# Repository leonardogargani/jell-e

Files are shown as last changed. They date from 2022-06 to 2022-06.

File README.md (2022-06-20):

# Jell-E

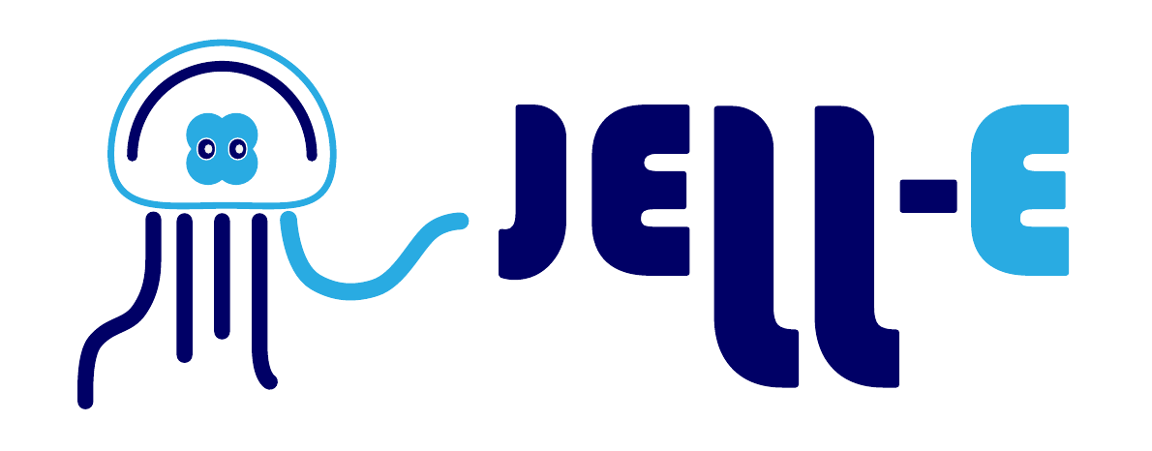
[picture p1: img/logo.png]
jell-e


Jell-E is a robot built for the Robotics & Design course at Politecnico di Milano, A.Y. 2021/2022.

The general theme of this year's edition is "Wearable Robot".

In particular, the goal is to make a robot able to engage interactions with third people, performing actions based on the behavior of both the wearer and other people.

To better know the Jell-E, take a look at:
- the [presentation slides](docs/presentation_slides.pdf)
- the [complete report](docs/complete_report.pdf)
- the [user manual](docs/user_manual.pdf)
- the [maintenance manual](docs/maintenance_manual.pdf)

## Repository structure

The repository is divided into the following directories:
- [esp32/](esp32/), containing the Arduino code that runs on the ESP32;
- [models/](models/), containing all the models (OpenSCAD and SolidWorks) for the parts of the robot;
- [schematic/](schematic/), containing the schematic of the circuit with all the sensors and actuators;
- [stl/](stl/), containing the STL files to print all the parts;
- [docs/](docs/), containing the user manual, the maintenance manual, some presentation slides, and the complete report.

## Team members

- Giorgio Brugali
- Alessandro Caruso
- Greta Corti
- Leonardo Gargani
- Yeran Liu

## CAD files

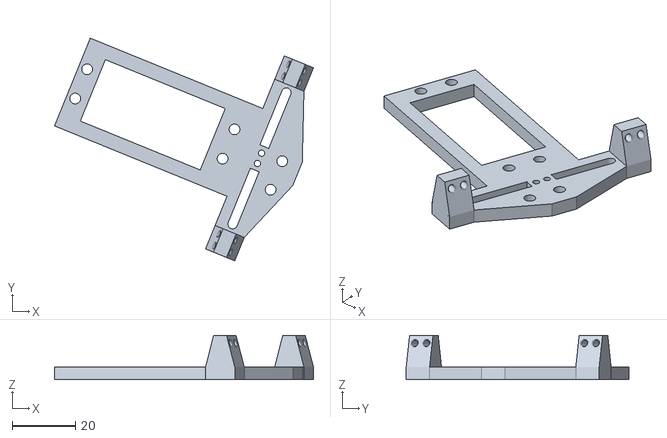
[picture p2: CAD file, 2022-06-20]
stl/solidworks/Assieme_Completo - ServoMotors_Main Adapter-2.STL
82.0 x 70.5 x 14.0

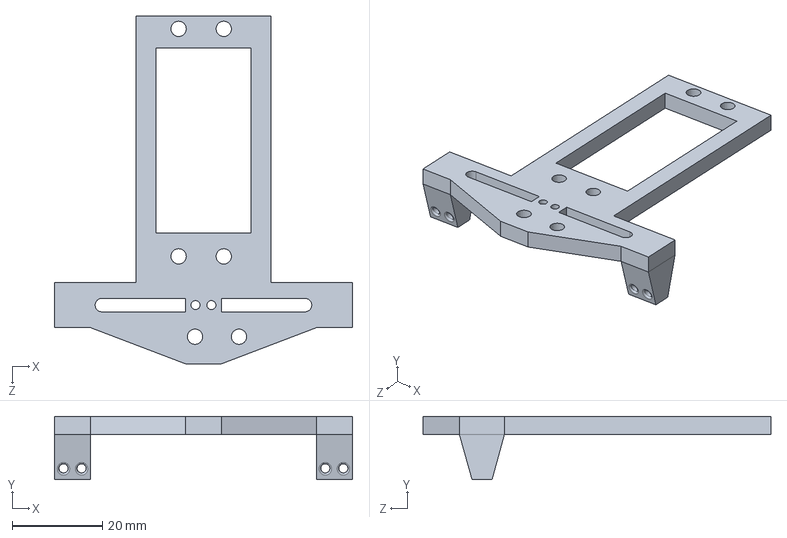
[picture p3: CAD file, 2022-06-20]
models/solidworks/ServoMotors_Main Adapter.SLDPRT
66.0 x 14.0 x 77.0 mm

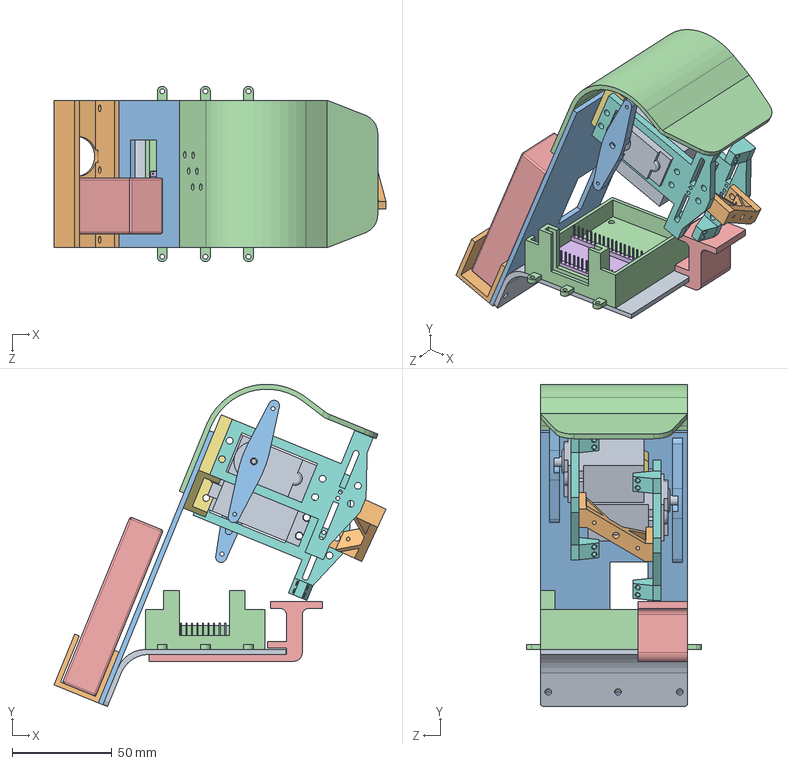
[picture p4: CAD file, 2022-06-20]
models/solidworks/Assieme_Completo.SLDASM
166.6 x 161.7 x 88.0 mm
Base_Shoulder Adapter
Cover_Battery and Switch
Cover_002 - Longer of 2.5
Cover_Upper Closure
External_Battery
Internal_ESP
ServoMotors_Adapter Back
ServoMotors_Main Adapter x 2
ServoMotor_Body x 2
ServoMotors_AdapterFront
ServoMotors_Adapter Wing x 2
Internal_Box_001
Extra Support

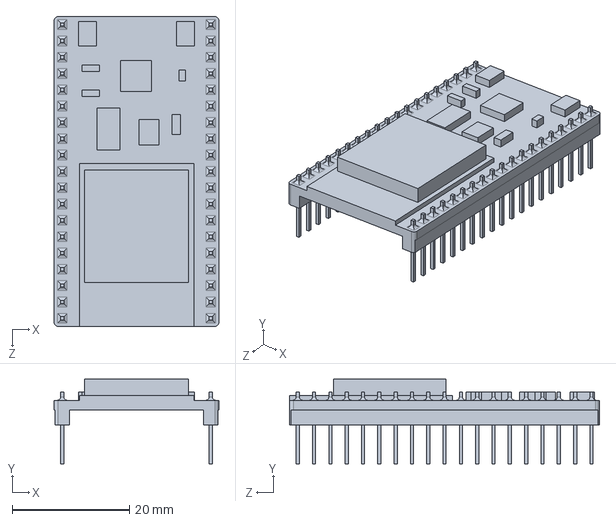
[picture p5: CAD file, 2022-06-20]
models/solidworks/Internal_ESP.SLDPRT
28.1 x 14.5 x 53.0 mm

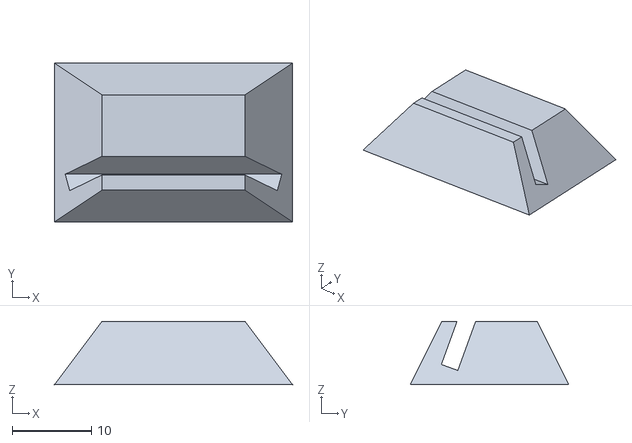
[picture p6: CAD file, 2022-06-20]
stl/openscad/plate_stand.stl
30.0 x 20.0 x 8.00

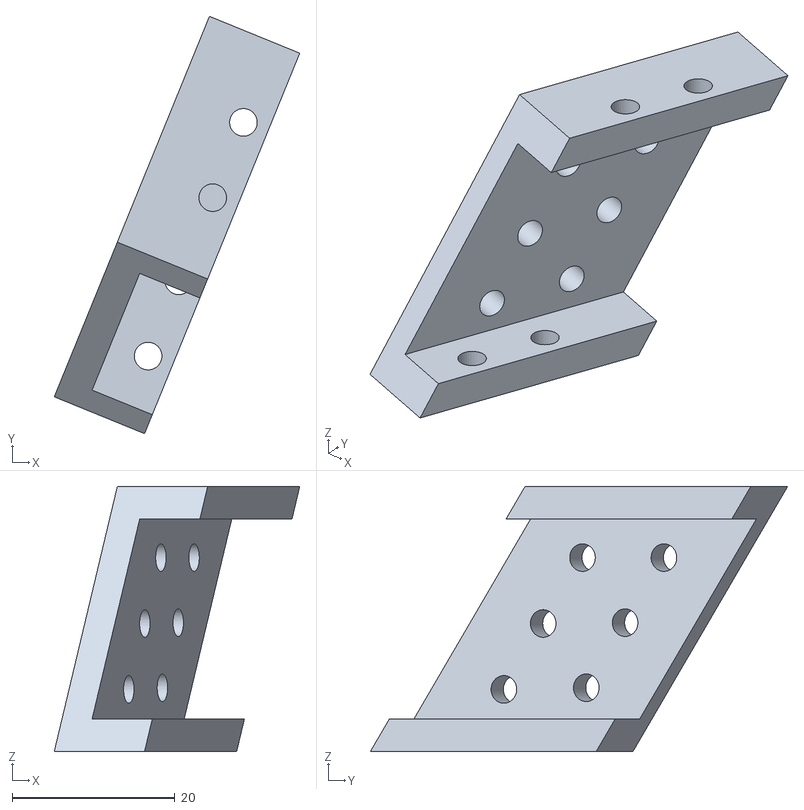
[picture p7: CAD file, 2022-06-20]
stl/solidworks/Assieme_Completo - ServoMotors_Adapter Back-1.STL
30.2 x 51.3 x 32.6

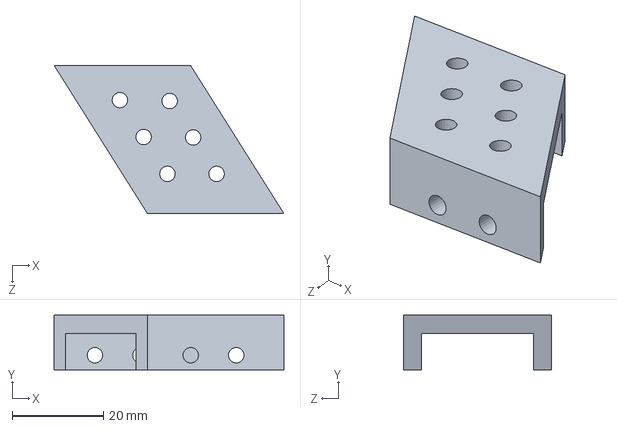
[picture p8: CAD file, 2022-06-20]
models/solidworks/ServoMotors_Adapter Back.SLDPRT
50.5 x 12.0 x 32.6 mm

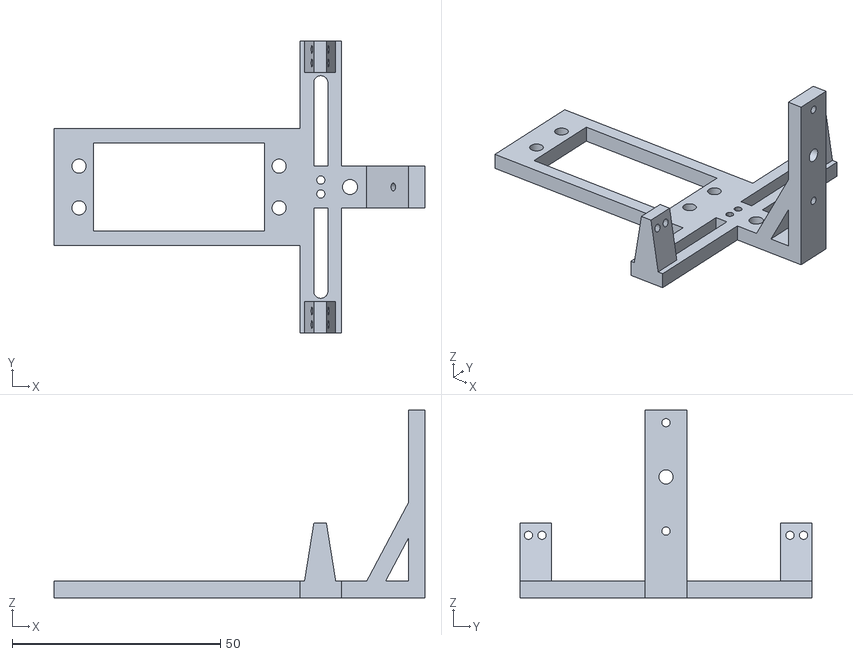
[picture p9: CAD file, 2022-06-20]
stl/openscad/servo_mount_high.stl
89.0 x 70.0 x 45.0

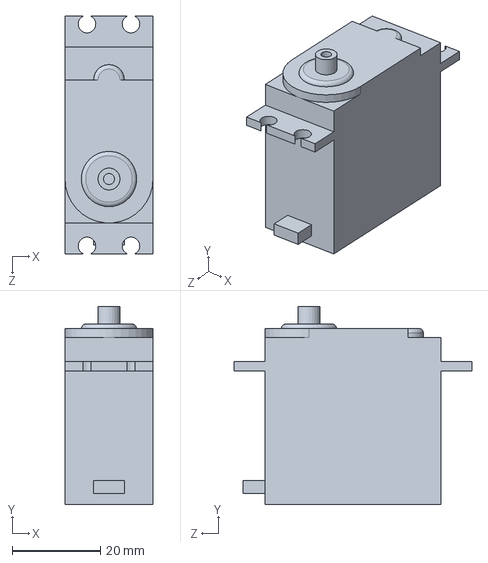
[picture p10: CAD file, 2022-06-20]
models/solidworks/ServoMotor_Body.SLDPRT
20.0 x 45.0 x 54.0 mm

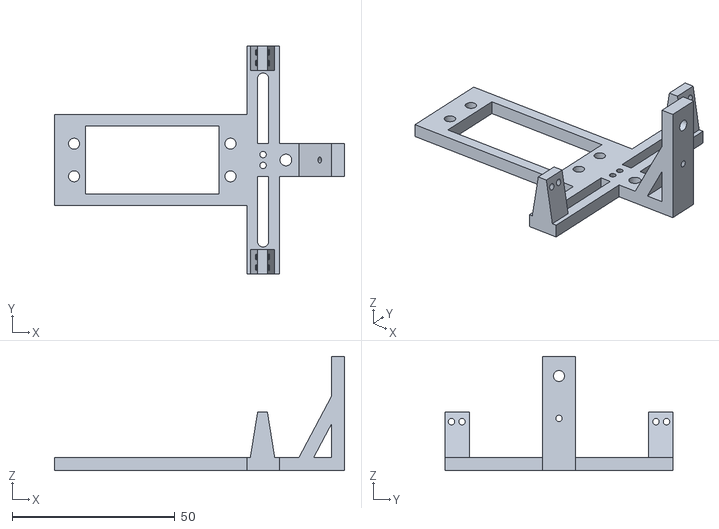
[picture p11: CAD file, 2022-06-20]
stl/openscad/servo_mount_low.stl
89.0 x 70.0 x 35.0

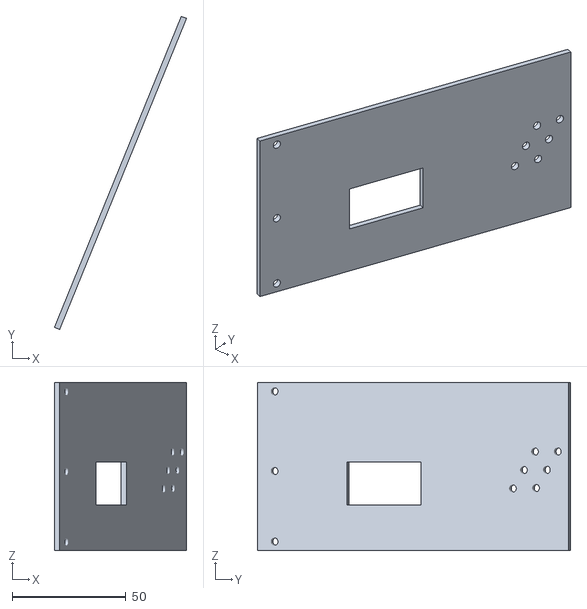
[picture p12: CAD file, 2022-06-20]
stl/solidworks/Assieme_Completo - Cover_002 - Longer of 2.5-1.STL
58.1 x 137.5 x 74.0

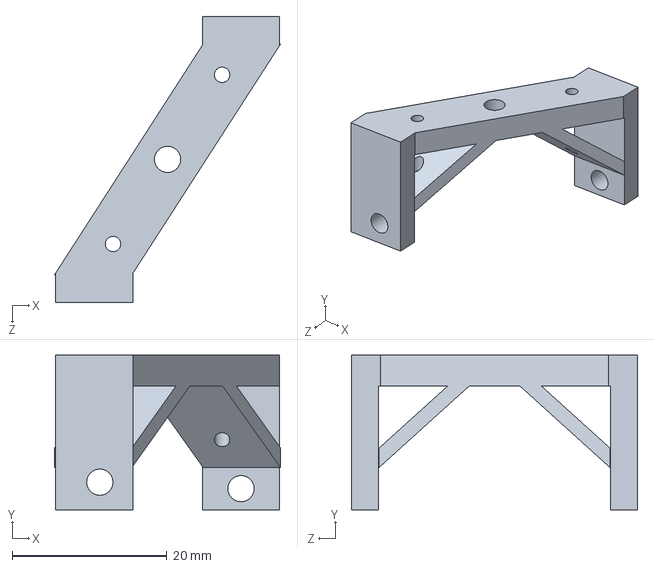
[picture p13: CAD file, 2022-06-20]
models/solidworks/ServoMotors_AdapterFront.SLDPRT
29.2 x 20.0 x 37.0 mm

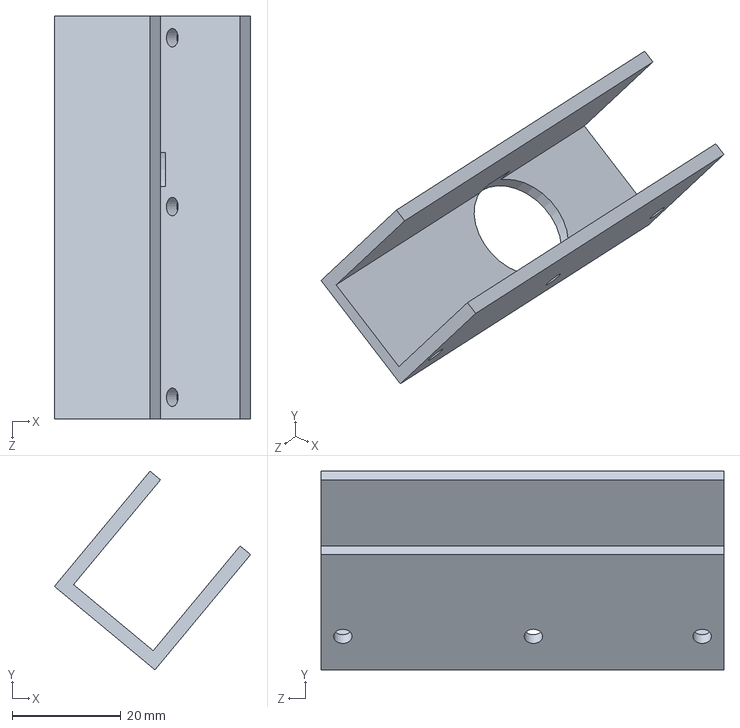
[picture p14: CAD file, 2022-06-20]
models/solidworks/Cover_Battery and Switch.SLDPRT
36.0 x 36.5 x 74.0 mm

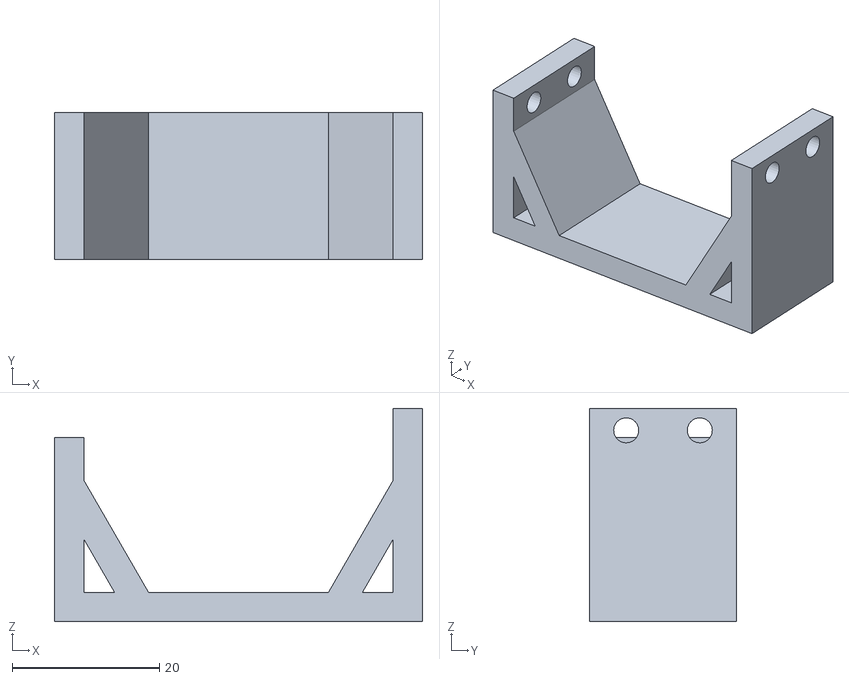
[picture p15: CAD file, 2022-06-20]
stl/openscad/arc_support.stl
50.0 x 20.0 x 29.0

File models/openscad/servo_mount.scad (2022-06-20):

include <lib/tentacle.scad>


servo_mount(high_vertical=false);

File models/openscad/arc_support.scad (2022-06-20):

include <lib/tentacle.scad>


arc_support();

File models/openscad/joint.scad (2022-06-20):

include <lib/tentacle.scad>


joint(joint_radius=16, last_joint=false);

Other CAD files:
stl/solidworks/Assieme_Completo - ServoMotors_Main Adapter-1.STL
stl/solidworks/Assieme_Completo - Internal_ESP-1.STL
stl/solidworks/Assieme_Completo - Cover_Upper Closure-1.STL
models/solidworks/Cover_002 - Longer of 2.5.SLDPRT
models/openscad/logo_plate.scad
models/openscad/plate_stand.scad
models/openscad/round_washer.scad
models/openscad/spring.scad
models/openscad/tip.scad
models/solidworks/Base_Shoulder Adapter.SLDPRT
models/solidworks/Cover_Upper Closure.SLDPRT
models/solidworks/External_Battery.SLDPRT
models/solidworks/Extra Support.SLDPRT
models/solidworks/Internal_Box_001.SLDPRT
stl/openscad/joint.stl
stl/openscad/logo_plate.stl
stl/openscad/round_washer.stl
stl/openscad/spring.stl
stl/solidworks/Assieme_Completo - Base_Shoulder Adapter-1.STL
stl/solidworks/Assieme_Completo - Cover_Battery and Switch-1.STL
stl/solidworks/Assieme_Completo - External_Battery-1.STL
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

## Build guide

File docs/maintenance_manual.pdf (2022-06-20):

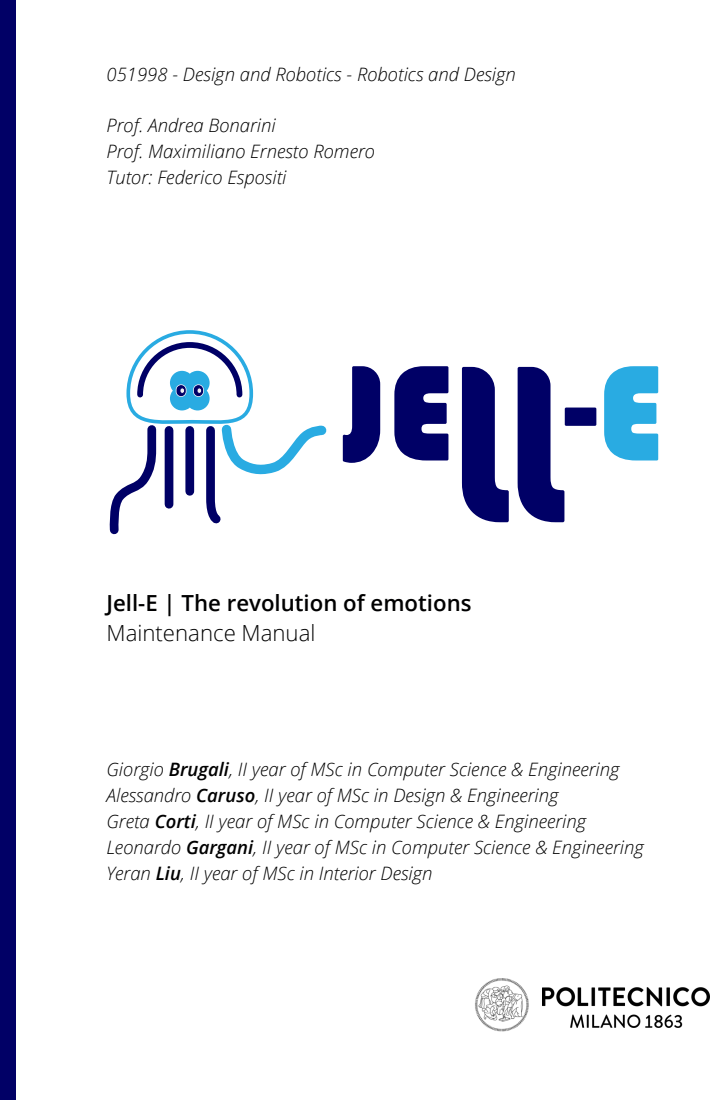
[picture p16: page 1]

051998 - Design and Robotics - Robotics and Design

Prof. Andrea Bonarini
Prof. Maximiliano Ernesto Romero
Tutor: Federico Espositi

Jell-E | The revolution of emotions
Maintenance Manual

Giorgio Brugali, II year of MSc in Computer Science & Engineering
Alessandro Caruso, II year of MSc in Design & Engineering
Greta Corti, II year of MSc in Computer Science & Engineering
Leonardo Gargani, II year of MSc in Computer Science & Engineering
Yeran Liu, II year of MSc in Interior Design

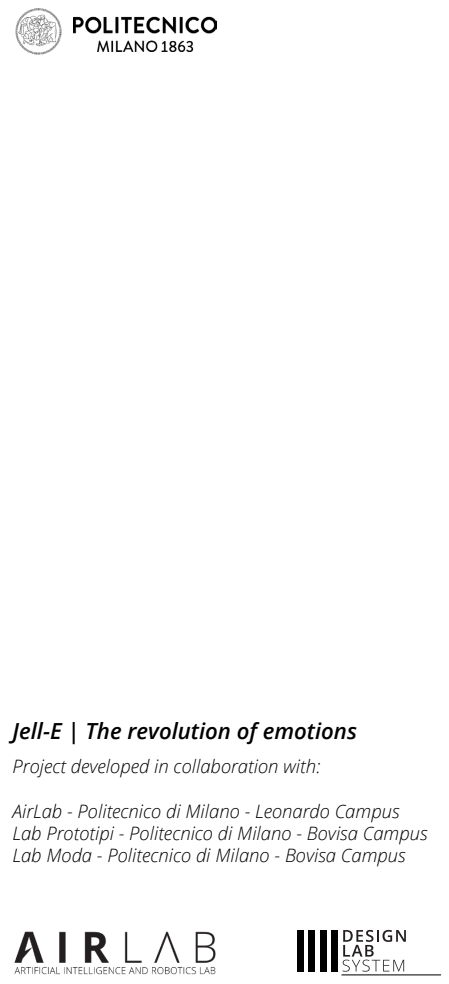
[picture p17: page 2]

Jell-E | The revolution of emotions
Project developed in collaboration with:
AirLab - Politecnico di Milano - Leonardo Campus
Lab Prototipi - Politecnico di Milano - Bovisa Campus
Lab Moda - Politecnico di Milano - Bovisa Campus

Jell-E | Maintenance Manual

### Circuit | Overview of the internal components Maintenance Manual

This manual aims at making the maintenance process simple. For an optimal analysis of the internal electrical components, a schematic diagram of the circuit is shown.

The complete circuit is composed by 2 servomotors; 1 LiPo battery (1700 mAh); 1 ESP board; 1 swtich; 1 step-down; 1 microphone, 1 limit switch (finecorsa - ITA); 10 LEDs on a RGB strip lights and 20 LEDs obtained

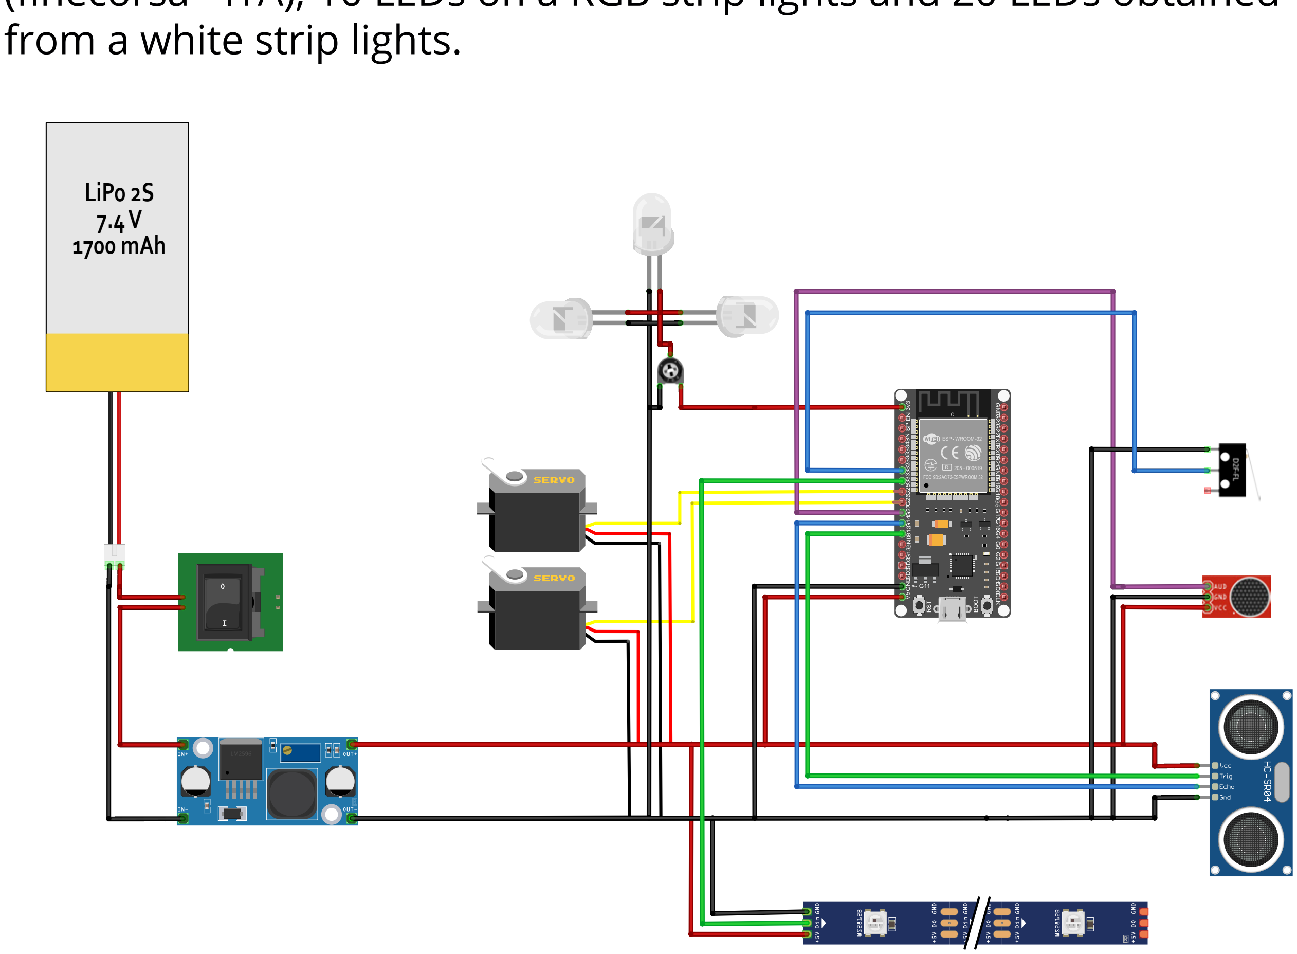
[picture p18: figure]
LiPo 2S 7.4 V 1700 mAh; from a white strip lights.

The battery needs to be recharged if it goes under 7.40 V otherwise the electronic circuit could not work properly. In case of battery change, place it correctly in the robot case as shown in the picture.
Connect the battery to its own connector and press the button under the case to turn on the robot. After 3 seconds from the switching the robot is ready to interact, as is possible to see the eyes leds start the “breath” gesture.

Remove the battery if the robot is going to be not used for a long time.

051998 - Robotics & Design - 2022

### Board | Pins and connectors Color code

Connections of sensors and actuators to the board are not interchangeable. To connect them correctly it is necessary to match the right colors (red, black, blue and white) and the same number of pins (two, three, and four) for each connector.

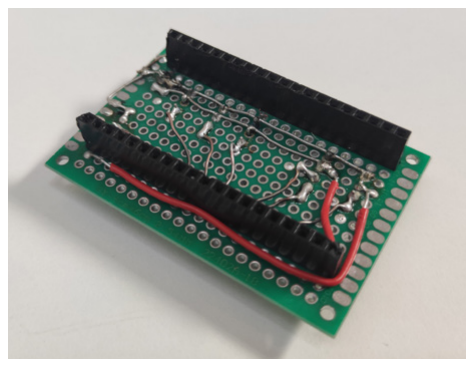
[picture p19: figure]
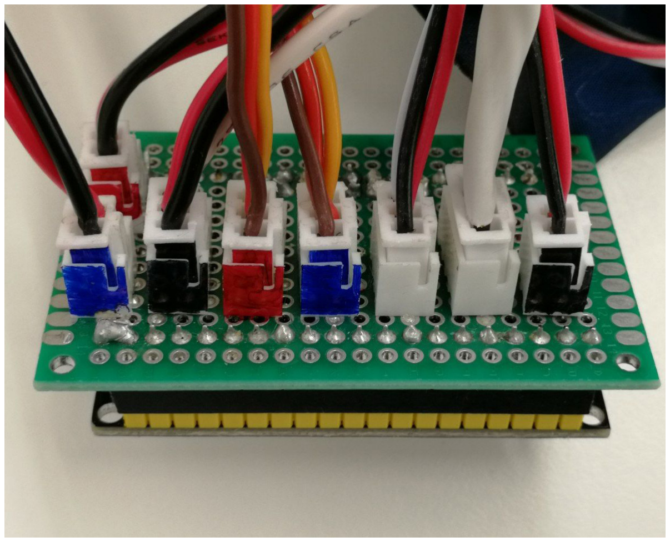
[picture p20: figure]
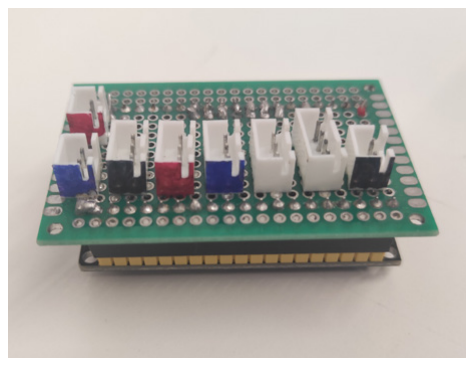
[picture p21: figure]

The existing 4-pins connector is the only one present on the board, and it is attached to the ultra sonic sensor. There are four 3-pins connectors and three 2-pins connector. The following scheme is provided to an optimal user experience.
1 - Limit switch
2 - Step down
3 - LED Strip
4 - Servo motor
5 - Servo motor
6 - Microphone
7 - Ultra sonic
8 - Lights

### JST connectors

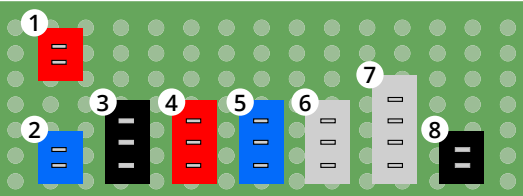
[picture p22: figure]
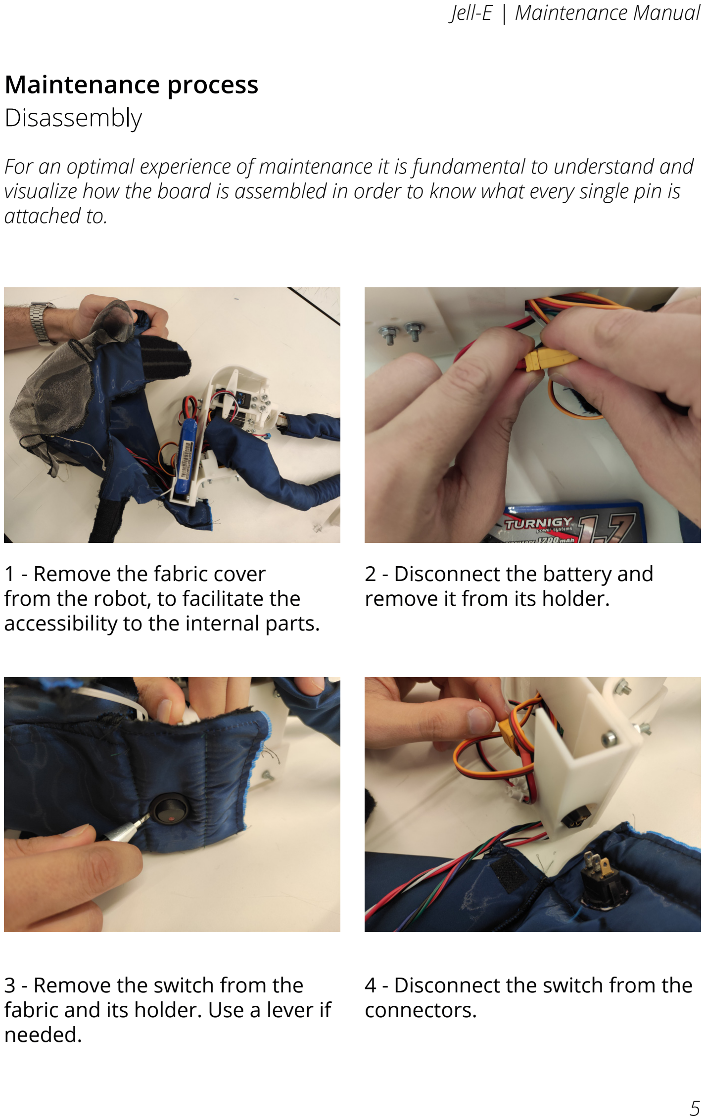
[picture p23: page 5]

Jell-E | Maintenance Manual

### Maintenance process Disassembly

For an optimal experience of maintenance it is fundamental to understand and visualize how the board is assembled in order to know what every single pin is attached to.

1 - Remove the fabric cover from the robot, to facilitate the accessibility to the internal parts.

3 - Remove the switch from the fabric and its holder. Use a lever if needed.

2 - Disconnect the battery and remove it from its holder.

4 - Disconnect the switch from the connectors.

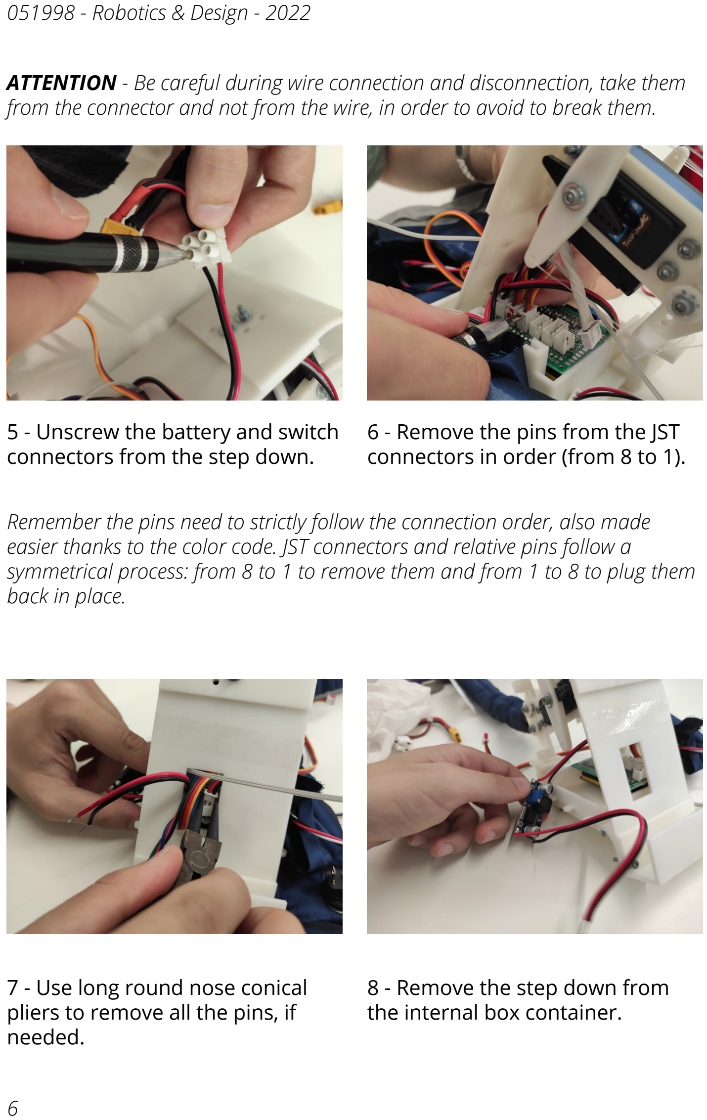
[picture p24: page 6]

051998 - Robotics & Design - 2022

ATTENTION - Be careful during wire connection and disconnection, take them from the connector and not from the wire, in order to avoid to break them.

Remember the pins need to strictly follow the connection order, also made easier thanks to the color code. JST connectors and relative pins follow a symmetrical process: from 8 to 1 to remove them and from 1 to 8 to plug them back in place.

5 - Unscrew the battery and switch
connectors from the step down.

7 - Use long round nose conical pliers to remove all the pins, if needed.

6 - Remove the pins from the JST connectors in order (from 8 to 1).

8 - Remove the step down from the internal box container.

Jell-E | Maintenance Manual

Bend a little bit the longer plastic plate with caution, and take out the stripboard. The microcontroller is connected above the stripboard, it is possible to remove it, be careful not to skew the pins. In case of reconnection, be careful to place with the right orientation, use as reference the red line of 5V.

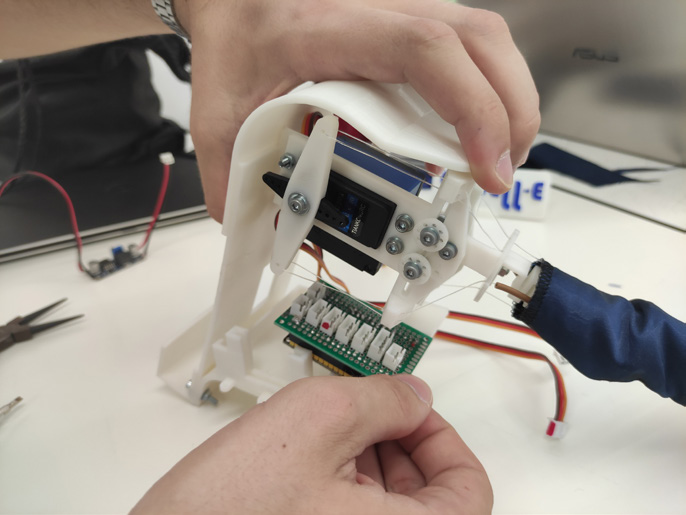
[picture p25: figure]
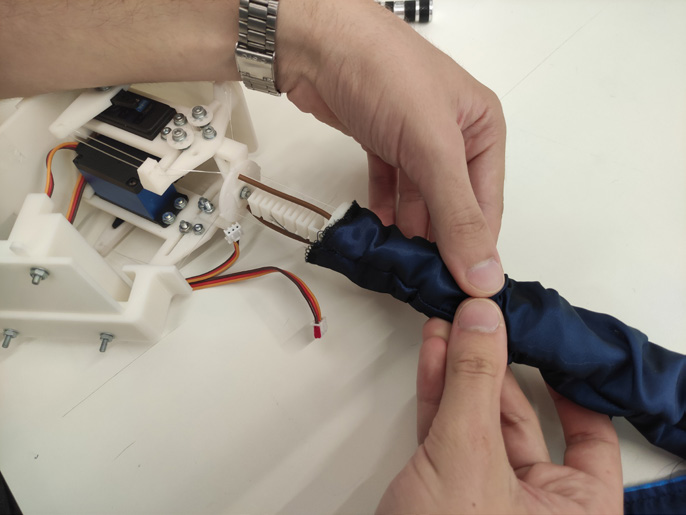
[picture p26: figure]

Due to the passage of time, fish lines that are connected to servos and used to control the mechanical tentacle movements may loosen. Use a screwdriver with the screws near the servo motors to regulate wire tensions.

9 - Remove the ESP board from
the box container, bending the
upper plate if needed.

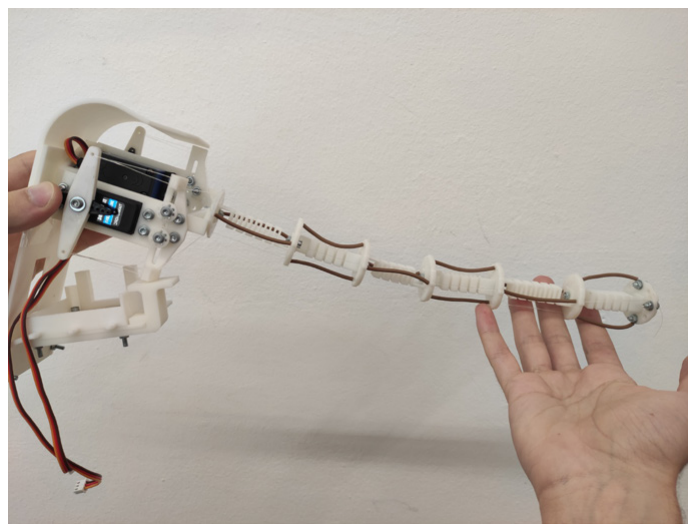
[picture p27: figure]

11 - Once you obtain the scheleton you can use a wrench to unscrew the internal nut that guides wires.

10 - Take off the covering fabric of the robotic tentacle. Pay attention to the nylon wires.

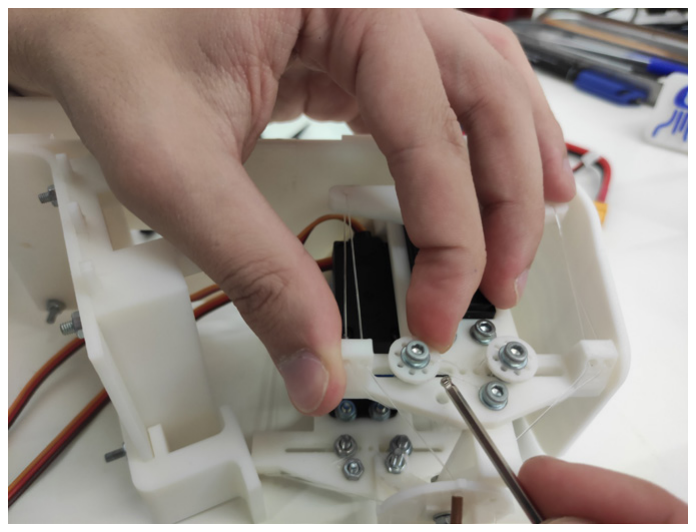
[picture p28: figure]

12 - Once loosen the nut, move the circular joint and move it along the rail to calibrate the tentacle.

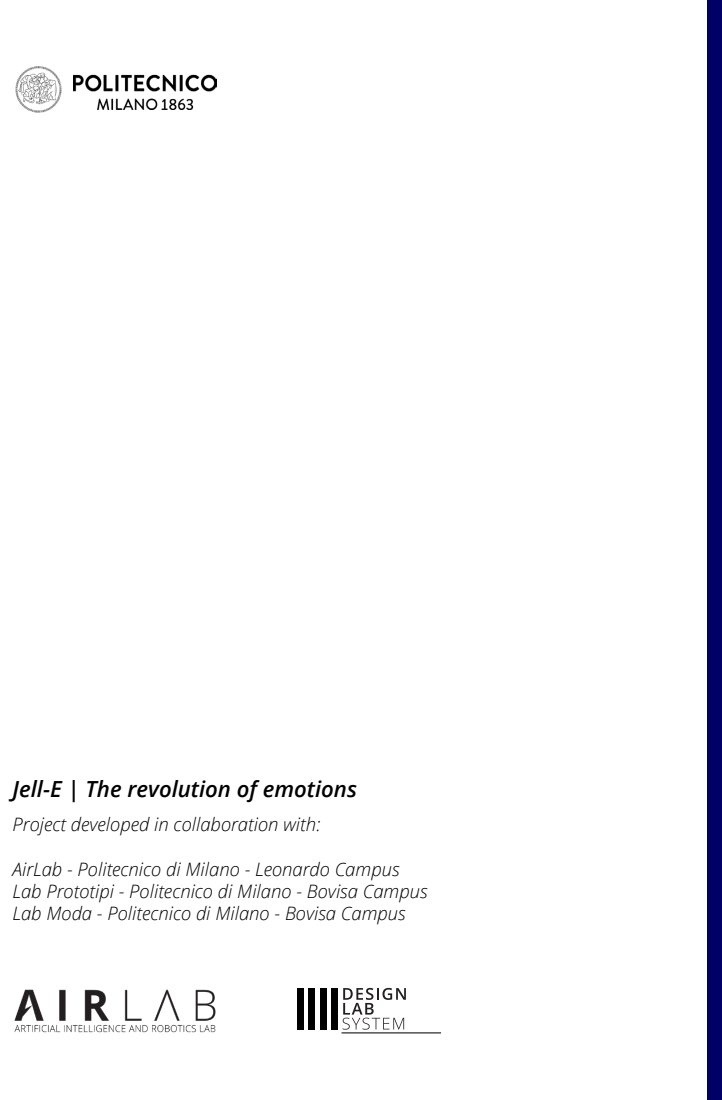
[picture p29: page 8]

Jell-E | The revolution of emotions
Project developed in collaboration with:
AirLab - Politecnico di Milano - Leonardo Campus
Lab Prototipi - Politecnico di Milano - Bovisa Campus
Lab Moda - Politecnico di Milano - Bovisa Campus

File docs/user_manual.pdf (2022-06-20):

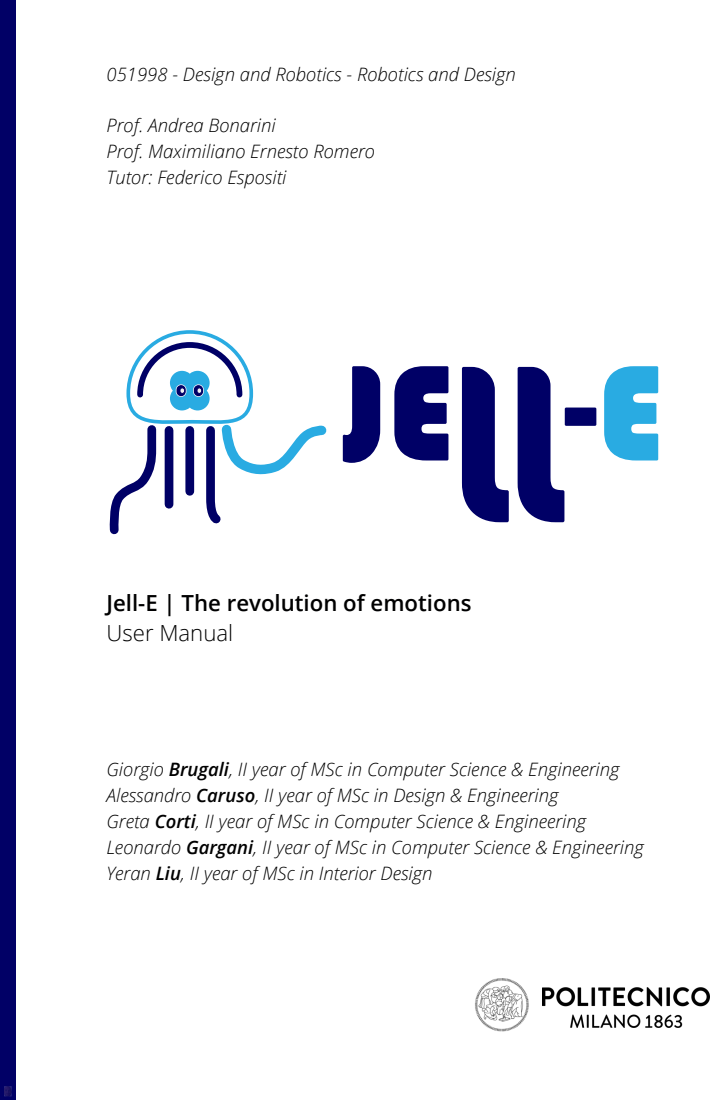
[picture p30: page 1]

051998 - Design and Robotics - Robotics and Design

Prof. Andrea Bonarini
Prof. Maximiliano Ernesto Romero
Tutor: Federico Espositi

Jell-E | The revolution of emotions
User Manual

Giorgio Brugali, II year of MSc in Computer Science & Engineering
Alessandro Caruso, II year of MSc in Design & Engineering
Greta Corti, II year of MSc in Computer Science & Engineering
Leonardo Gargani, II year of MSc in Computer Science & Engineering
Yeran Liu, II year of MSc in Interior Design


Jell-E | The revolution of emotions
Project developed in collaboration with:
AirLab - Politecnico di Milano - Leonardo Campus
Lab Prototipi - Politecnico di Milano - Bovisa Campus
Lab Moda - Politecnico di Milano - Bovisa Campus

Jell-E | User Manual

### Jell-E | User Journey User Manual

Jell-E is a wearable robot: it aims to be a mean for kids to communicate and express themselves. It can be considered as a called transitional object: the rapresentation of an object which kids use to make a transition from childhood to a first approach to the interactive world with others.

Jell-E has 2 eyes, which will recognize movement and proximity; a robotic tentacle, which will move according to the interactions provided, a long squeezable tentacle, with a botton on the tip and a microphone close to your shoulder to detect high sounds, lights around the eyes, which will change color according to the emotions Jell-E is feeling.

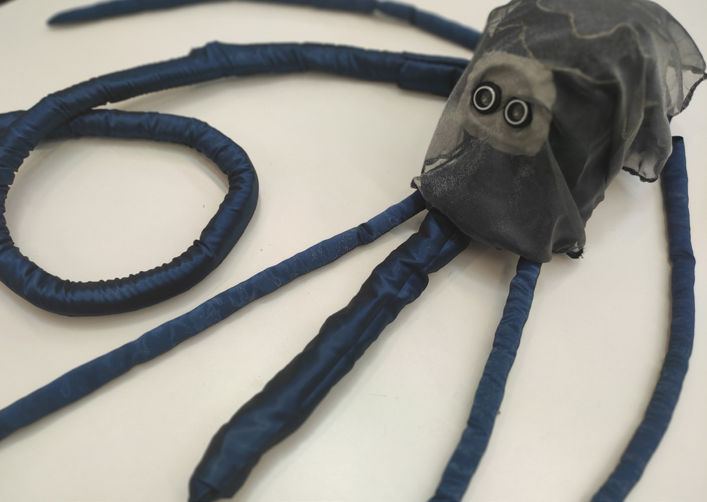
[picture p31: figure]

In this user manual you will find a precise guide which will explain in detail all the features of Jell-E, from how to dress it to how to make it work. The manual is intended for adults, to let them explain how to play with Jell-E and have an optimal experience.

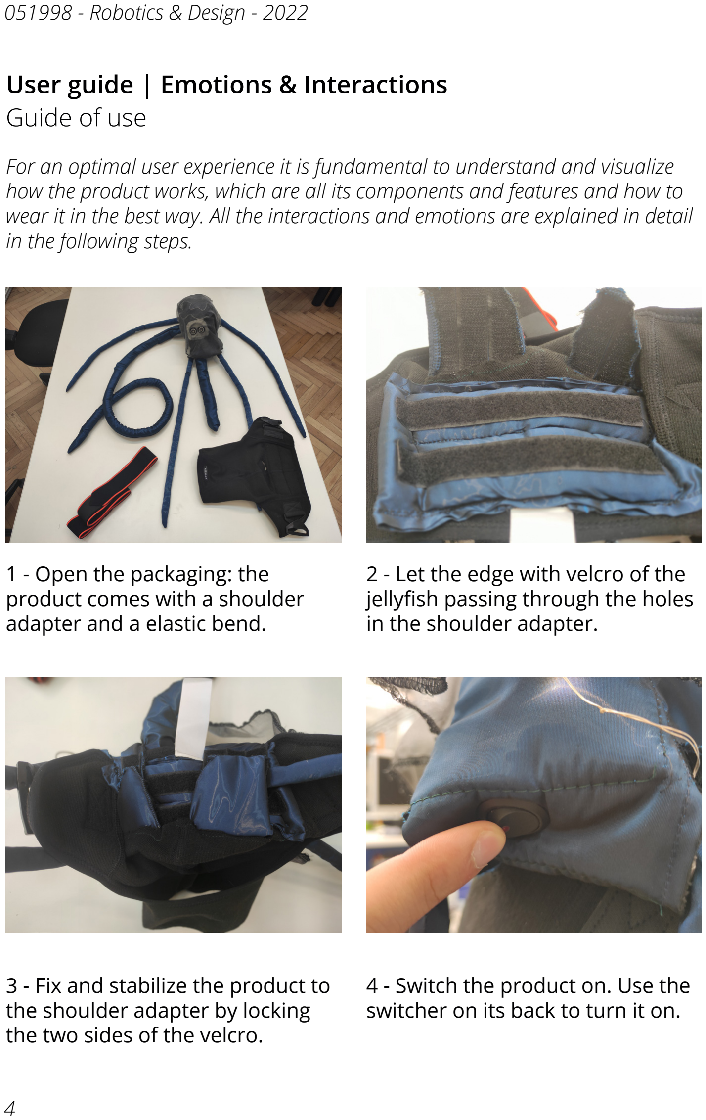
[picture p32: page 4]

051998 - Robotics & Design - 2022

### User guide | Emotions & Interactions Guide of use

For an optimal user experience it is fundamental to understand and visualize how the product works, which are all its components and features and how to wear it in the best way. All the interactions and emotions are explained in detail in the following steps.

1 - Open the packaging: the product comes with a shoulder adapter and a elastic bend.

3 - Fix and stabilize the product to the shoulder adapter by locking the two sides of the velcro.

2 - Let the edge with velcro of the jellyfish passing through the holes in the shoulder adapter.

4 - Switch the product on. Use the switcher on its back to turn it on.

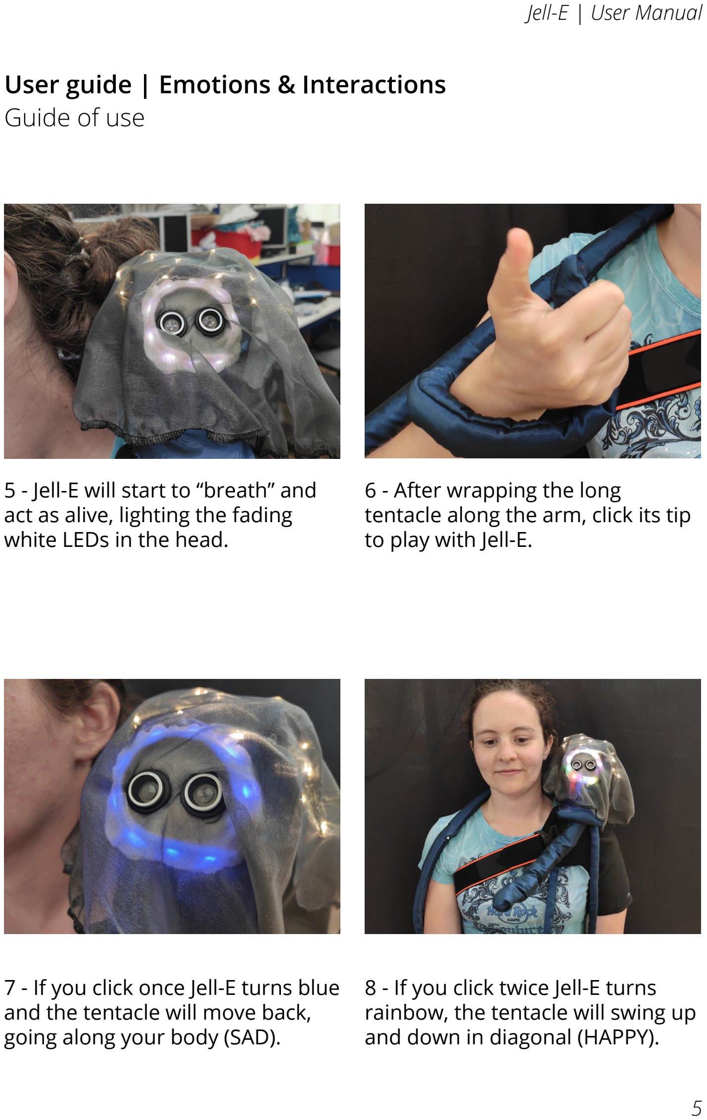
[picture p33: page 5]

Jell-E | User Manual

### User guide | Emotions & Interactions Guide of use

5 - Jell-E will start to “breath” and act as alive, lighting the fading white LEDs in the head.

7 - If you click once Jell-E turns blue and the tentacle will move back, going along your body (SAD).

6 - After wrapping the long tentacle along the arm, click its tip to play with Jell-E.

8 - If you click twice Jell-E turns rainbow, the tentacle will swing up and down in diagonal (HAPPY).

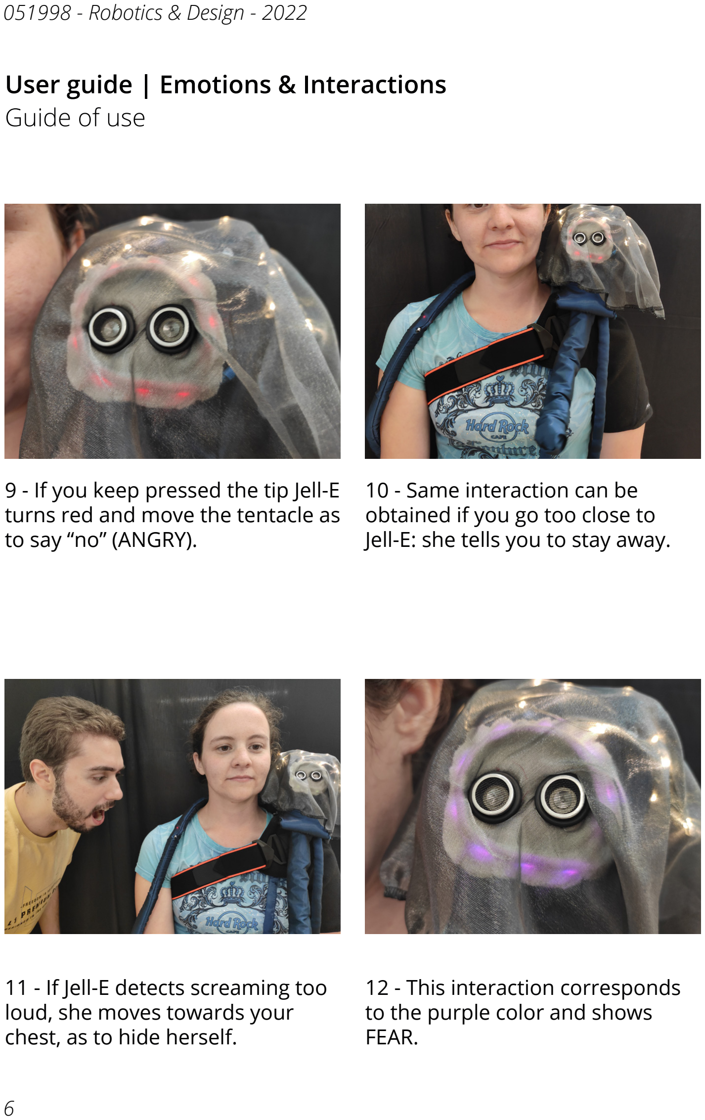
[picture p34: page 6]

051998 - Robotics & Design - 2022

9 - If you keep pressed the tip Jell-E turns red and move the tentacle as to say “no” (ANGRY).

11 - If Jell-E detects screaming too loud, she moves towards your chest, as to hide herself.

10 - Same interaction can be obtained if you go too close to Jell-E: she tells you to stay away.

12 - This interaction corresponds to the purple color and shows FEAR.

### User guide | Emotions & Interactions Guide of use

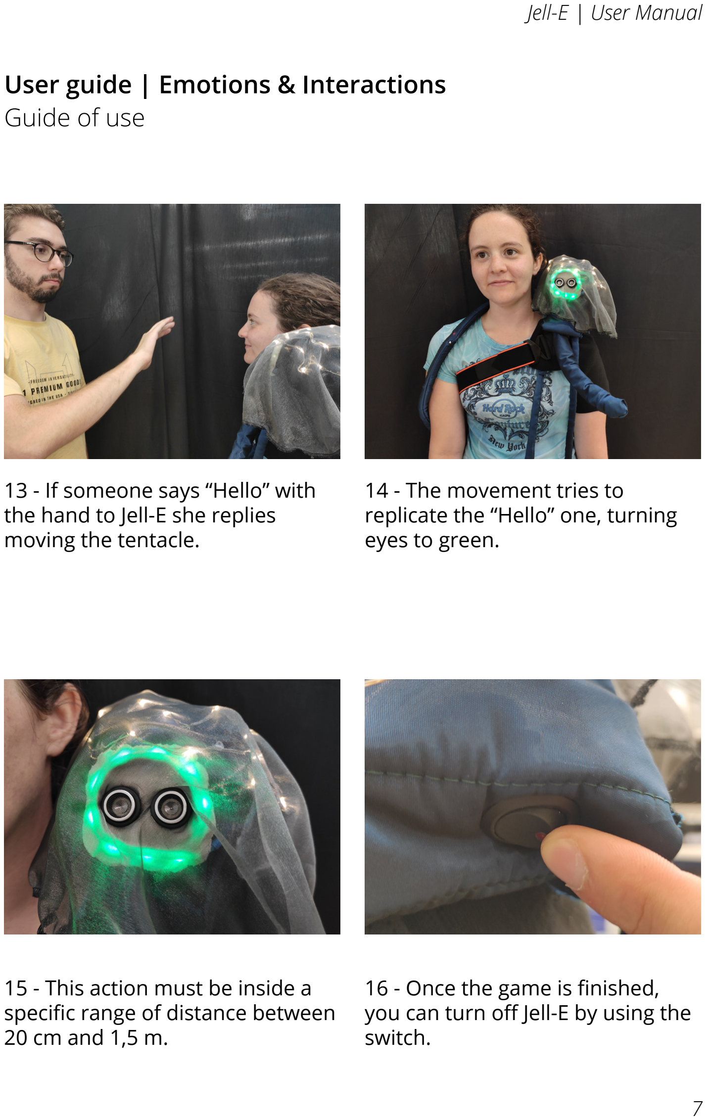
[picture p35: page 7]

Jell-E | User Manual

13 - If someone says “Hello” with the hand to Jell-E she replies moving the tentacle.

15 - This action must be inside a specific range of distance between 20 cm and 1,5 m.

14 - The movement tries to replicate the “Hello” one, turning eyes to green.

16 - Once the game is finished, you can turn off Jell-E by using the switch.

### User guide | Emotions & Interactions Guide of use


Jell-E | The revolution of emotions
Project developed in collaboration with:
AirLab - Politecnico di Milano - Leonardo Campus
Lab Prototipi - Politecnico di Milano - Bovisa Campus
Lab Moda - Politecnico di Milano - Bovisa Campus

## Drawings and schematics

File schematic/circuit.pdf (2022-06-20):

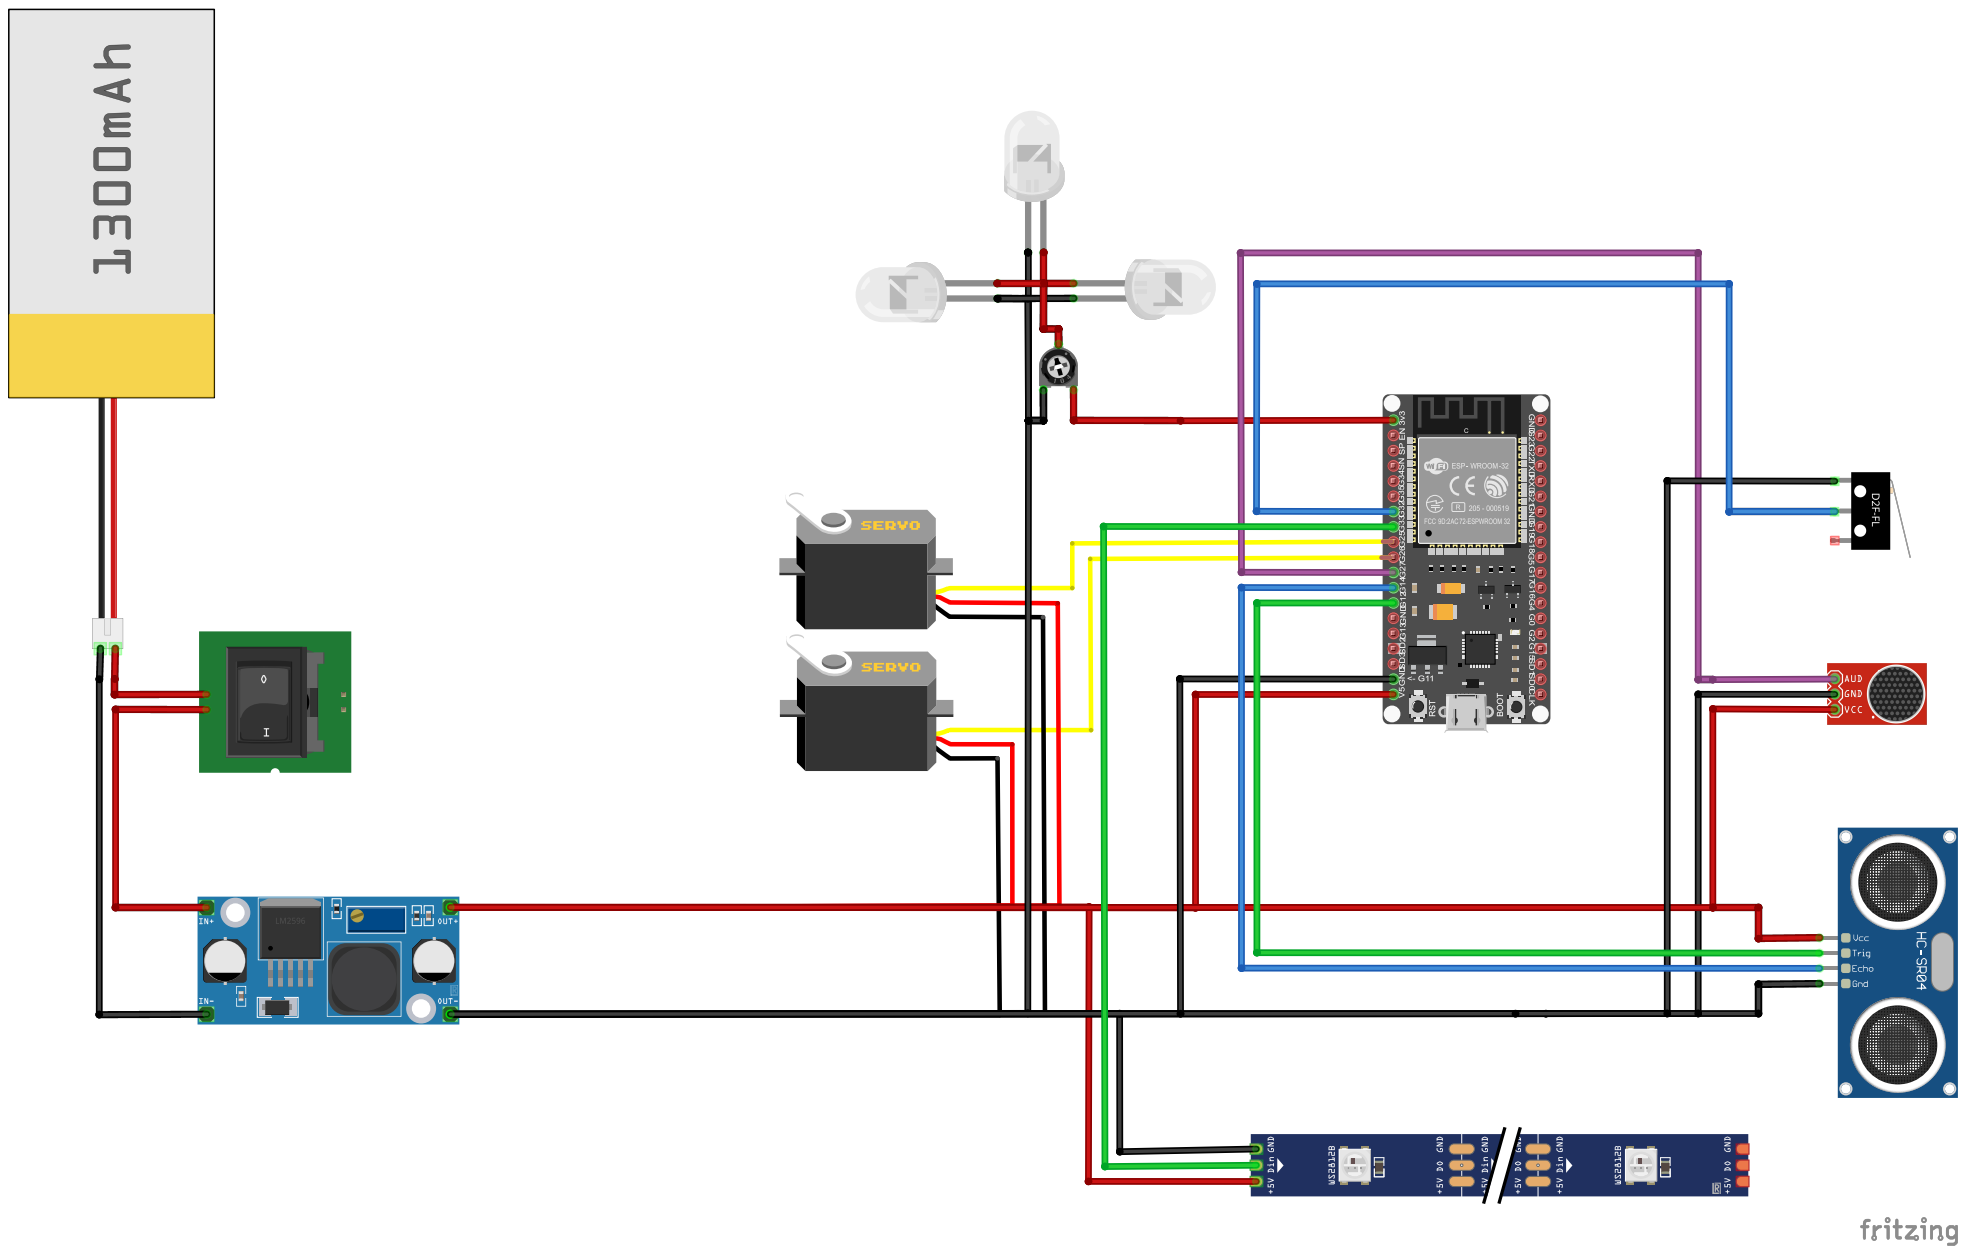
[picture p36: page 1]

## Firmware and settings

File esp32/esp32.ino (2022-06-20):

#include "Arduino.h"
#include "ServoEasing.hpp"
#include "Include/Devices.h"

#define ACTION_TIME 5000
#define WAITING_TIME 2000


// Objects that defines our sensors and actuators
Button button; 
Microphone mic_sensor;
UltrasonicSensor distance_sensor;
LEDStrip led_strip;
Tentacle tentacle;

unsigned long last_timestamp = 0;
unsigned long start_action_millis = 0;
unsigned long end_action_millis = 0;
int squeezes = 0;

// Flag used to disable sensors while a gesture is working
bool disable = false;

// Flags used to say which emotion is in use
bool hello_in_use = false;
bool stay_away_in_use = false;
bool curious_in_use = false;
bool scared_in_use = false;
bool can_breathe = true;


void setup()
{
  button.setup();
  mic_sensor.setup();
  distance_sensor.setup();
  led_strip.setup();
  tentacle.setup();
  delay(3000);
}


/**
 * @brief Function that detects and reacts to button pressure.
 * 
 */ 
void detectionPressure()
{
  if (!disable) {
    int button_state = button.readPress();
    if (button_state == 0 && (millis() - button.getLastDebounce()) > DEBOUNCE) {
      disable = true;
      can_breathe = false;
      last_timestamp = millis();
      button.setLastDebounce(last_timestamp);
      button.updatePressCounter(); // 1

      // Check if we have a second touch in 2 seconds
      while (millis() - last_timestamp < WAITING_TIME) {
        if (millis() - button.getLastDebounce() > DEBOUNCE) {
          button_state = button.readPress();
          if (button_state == 0) {
            // Touched twice
            start_action_millis = millis();
            button.setLastDebounce(millis());
            button.updatePressCounter(); // 2
            break;
          }
        }
      }

      // Check if we have a long press
      last_timestamp = millis();
      while (millis() - last_timestamp < WAITING_TIME / 4) {
        if (millis() - button.getLastDebounce() > DEBOUNCE) {
          button_state = button.readPress();
          if (button_state == 0) {
            // Long press
            start_action_millis = millis();
            button.setLastDebounce(millis());
            button.updatePressCounter(); // 3
            break;
          }
        }
      }
    }
  }

  squeezes = button.getPressCounter();
  switch (squeezes)
  {
  case 1:
    // Happy Gesture (one press)
    led_strip.sad();
    tentacle.sad();
    break;
  case 2:
    // Sad Gesture (two presses)
    led_strip.happy();
    tentacle.happy();
    break;
  case 3:
    // Angry Gesture (long press)
    led_strip.angry();
    tentacle.angry();
    break;
  }

  // Reset everything after the action is ended
  if (squeezes > 0) {
    if (millis() - start_action_millis > ACTION_TIME) {
      button.resetPressCounter();
      disable = false;
      can_breathe = true;
      tentacle.reset();
      led_strip.reset();
      end_action_millis = millis();
    }
  }
}


/**
 * @brief Function that detects and reacts to microphone readings.
 * 
 */
void detectSound()
{
  if (!disable) {
    int mic_read = mic_sensor.readMic();
    if (abs(mic_read - mic_sensor.computeAverage()) >= LOUD) {
      // Scared Gesture
      scared_in_use = true;
      disable = true;
      can_breathe = false;
      start_action_millis = millis();
      led_strip.scared();
      tentacle.scared();
    }
  }

  if (scared_in_use) {
    if (millis() - start_action_millis > ACTION_TIME) {
      scared_in_use = false;
      disable = false;
      can_breathe = true;
      tentacle.reset();
      led_strip.reset();
      end_action_millis = millis();
    }
  }
}


/**
 * @brief Function that detect and react to Ultrasonic sensor readings.
 * 
 */
void detectDistance()
{
  if (!disable) {
    int distance_read = distance_sensor.readDistance();
    distance_sensor.updateSwingCounter(distance_read);
    // Say Hello
    if (distance_sensor.getSwingCounter() >= MIN_SWING) {
      // Actions for saying hello
      hello_in_use = true;
      disable = true;
      can_breathe = false;
      start_action_millis = millis();
      distance_sensor.resetSwingCounter();
    }
    // Too near
    if (distance_read < MIN_DISTANCE) {
      // Stay away actions
      distance_sensor.resetSwingCounter();
      led_strip.angry();
      stay_away_in_use = true;
      disable = true;
      can_breathe = false;
      start_action_millis = millis();
    }
}

  if (hello_in_use) {
    led_strip.hello();
    tentacle.sayHi();
  } else if (stay_away_in_use) {
    tentacle.angry();
}

if (hello_in_use || stay_away_in_use) {
    if (millis() - start_action_millis > ACTION_TIME) {
        hello_in_use = false;
        stay_away_in_use = false;
        disable = false;
        can_breathe = true;
        distance_sensor.resetSwingCounter();
        tentacle.reset();
        led_strip.reset();
        end_action_millis = millis();
    }
  }
}

int swing_counter = 0;
int previous_distance = 0;


void loop()
{
  /************TOUCH CONTROL************/
  detectionPressure();

  /************SOUND CONTROL************/
  detectSound();

  /************DISTANCE CONTROL*********/
  detectDistance();

  /************BREATH CONTROL***********/
  if (can_breathe) {
    led_strip.breath();
  }

}

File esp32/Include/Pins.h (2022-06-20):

#ifndef PINS_H
#define PINS_H

// Tentacle
#define SERVO_1_PIN 25 // vertical
#define SERVO_2_PIN 26 // horizontal

// Addressable led
#define LED_PIN 33

// Ultrasonic sensor
#define TRIGGER_PIN 12
#define ECHO_PIN 14

// Capacitive sensor
#define BUTTON_PIN 32

// Microphone
#define MIC_PIN 27

#endif

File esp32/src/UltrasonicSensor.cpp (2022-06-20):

#include "Arduino.h"
#include "../Include/Sensors/UltrasonicSensor.h"


/** 
 * @brief Construct a new Ultrasonic::Ultrasonic object 
 * 
 */
UltrasonicSensor::UltrasonicSensor() : duration(0), swing_counter(0), previous_distance(0), last_update(0)
{
}


/**
 * @brief Setup ultrasonic sensor pins. Echo pin as input and trigger pin as output.
 * 
 */
void UltrasonicSensor::setup()
{
  pinMode(TRIGGER_PIN, OUTPUT);
  pinMode(ECHO_PIN, INPUT);
  previous_distance = this->readDistance();
}


/**
 * @brief Read the distance detected from the ultrasonic sensor.
 * The function send a signal through the trigger pin and then read the time of flight from 
 * the echo pin. The distance is calculated with the following formula:
 * duration*sound_speed / 2.
 * @return Distance read in centimeter.
 * 
 */ 
int UltrasonicSensor::readDistance()
{
  int distance;
  digitalWrite(TRIGGER_PIN, LOW);
  delayMicroseconds(2);
  digitalWrite(TRIGGER_PIN, HIGH);
  delayMicroseconds(100);
  digitalWrite(TRIGGER_PIN, LOW);
  duration = pulseIn(ECHO_PIN, HIGH);
  distance = duration * 0.034 / 2;
  if (distance >= 1000 || distance == 0) {
    distance = previous_distance;
  }
  return distance;
}


/**
 * @brief Get the number of current swings detected.
 * @return the number of current swings detected.
 * 
 */
int UltrasonicSensor::getSwingCounter()
{
  return swing_counter;
}


/**
 * @brief Reset the number of swing detected.
 * 
 */ 
void UltrasonicSensor::resetSwingCounter()
{
  swing_counter = 0;
}

/**
 * @brief Update the current number of swing detected.
 * This function is used to trigger the sayHello gesture.
 * A swing is detected if in less than 1.5 meters there is a variation of measurment of 20 centimeters.
 * 
 */ 
void UltrasonicSensor::updateSwingCounter(int distance)
{

  if (millis() - last_update > 500 && ((distance - previous_distance) > DELTA_DISTANCE) && distance < 150) {
    last_update = millis();
    swing_counter++; 
  } if (distance > MAX_DISTANCE) //if someone goes away reset the swing_counter
    swing_counter = 0;
  previous_distance = distance;
}
